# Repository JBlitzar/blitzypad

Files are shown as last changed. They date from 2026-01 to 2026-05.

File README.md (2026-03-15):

# blitzypad

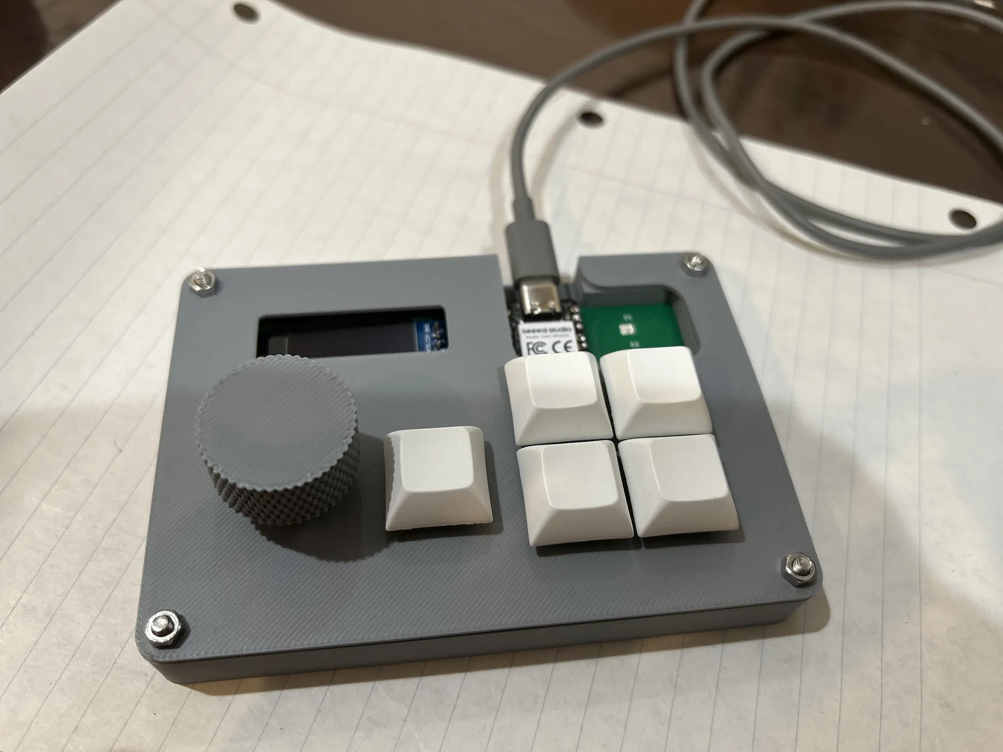
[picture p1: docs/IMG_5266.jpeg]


My starter hackpad project for Blueprint! Has four keys in a grid, an extra key, a rotary encoder, and a 128x32 OLED screen.

I don't have a screenshot of my overall project because it doesn't exist physically yet.

I plan to use this for all sorts of things! General use, sure. Probably also music production with that cool rotary encoder (time scrub / volume control). Or maybe even something like gaming or video editing! That's the beauty of circuitpython. It's really easy and you don't have to reflash every time. I may even try to have some dynamic things on the OLED screen down the line... After all, rp2040 can act as an arbitrary usb device! I've [done](https://github.com/JBlitzar/pd-usb-uvc) [some](https://github.com/JBlitzar/picoducky) [projects](https://github.com/JBlitzar/pd-quad-draw) with those as a part of picoducky ysws. This is really cool because we've got some additional hardware IO (namely the keys, rotary encoder, leds, and screen.)

<table width="100%">
    <tr>
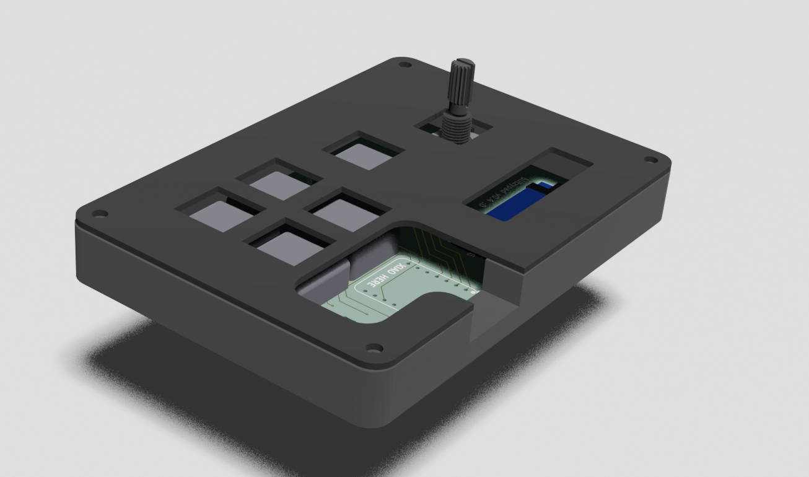
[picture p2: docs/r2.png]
    <td></td>
        <td>
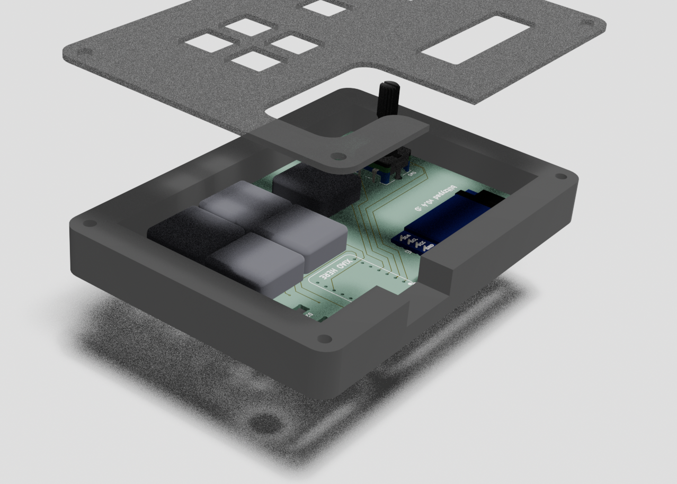
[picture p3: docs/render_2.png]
            
        </td>
        <td>
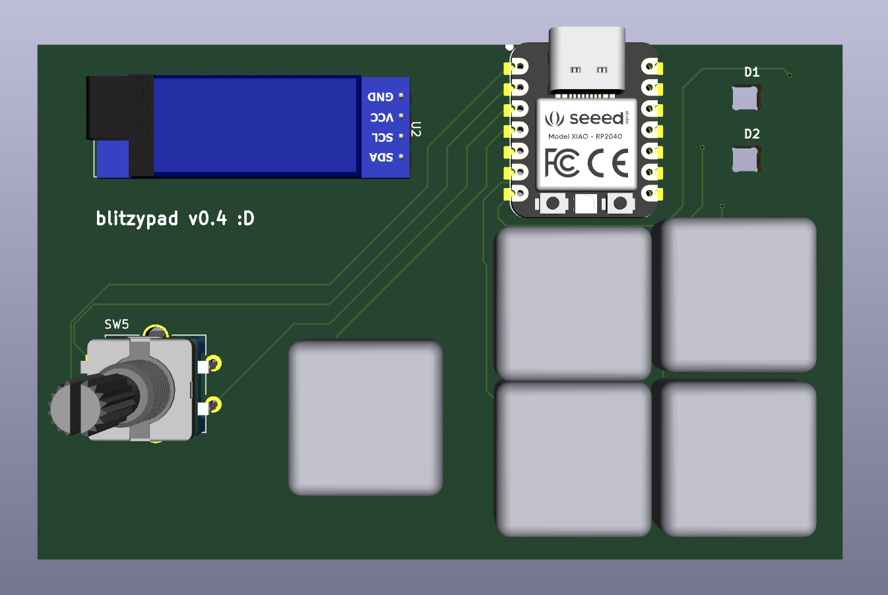
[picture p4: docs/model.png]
            
        </td>
    </tr>
</table>

## Case

_made in Fusion 360_
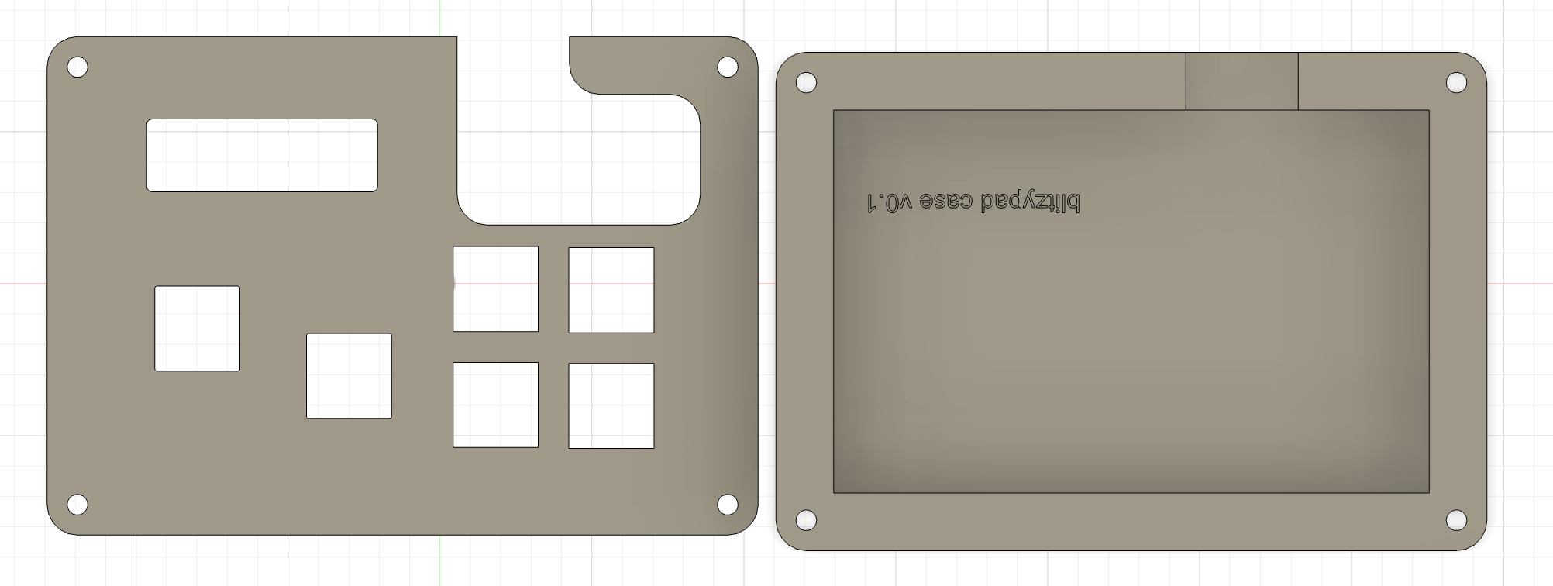
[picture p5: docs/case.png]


I have access to a laser cutter + 3d printer, so I won't need these to be shipped.

## Schematic

_made in Kicad_

### PCB:

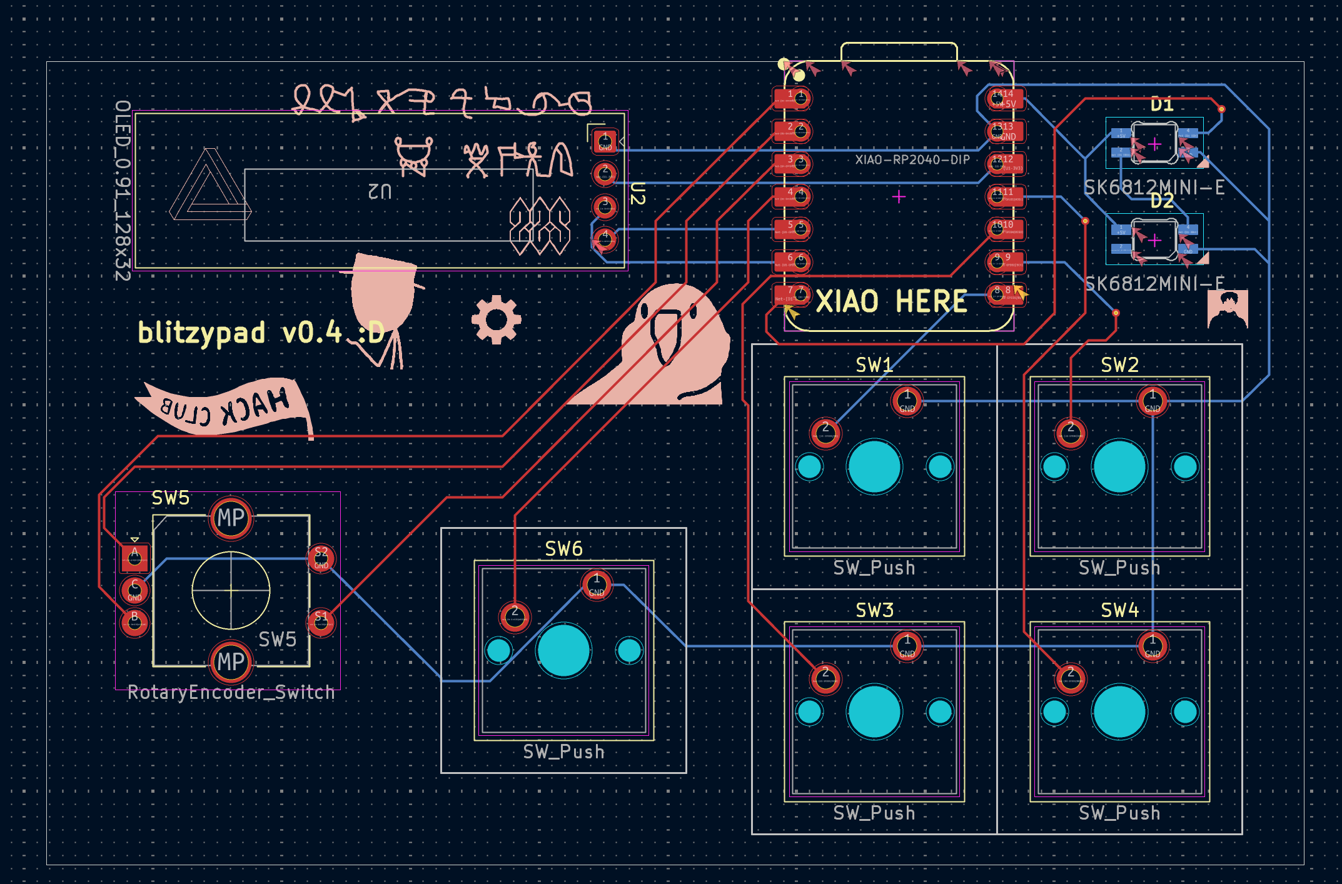
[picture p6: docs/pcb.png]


> I had some fun with the graphics, haha

_clean PCB without silkscreen:_

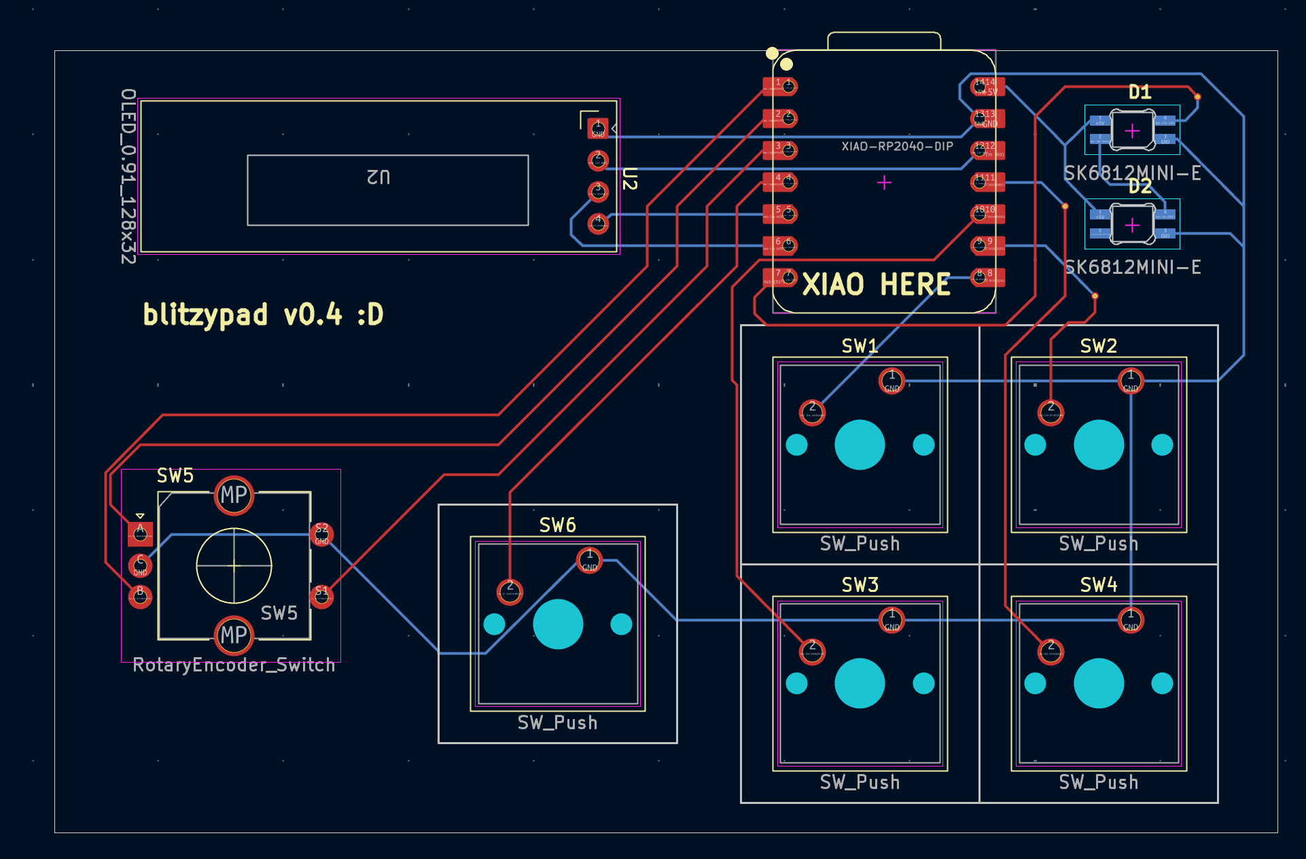
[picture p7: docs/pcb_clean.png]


### Schematic:

> (sorry it's a bit messy)

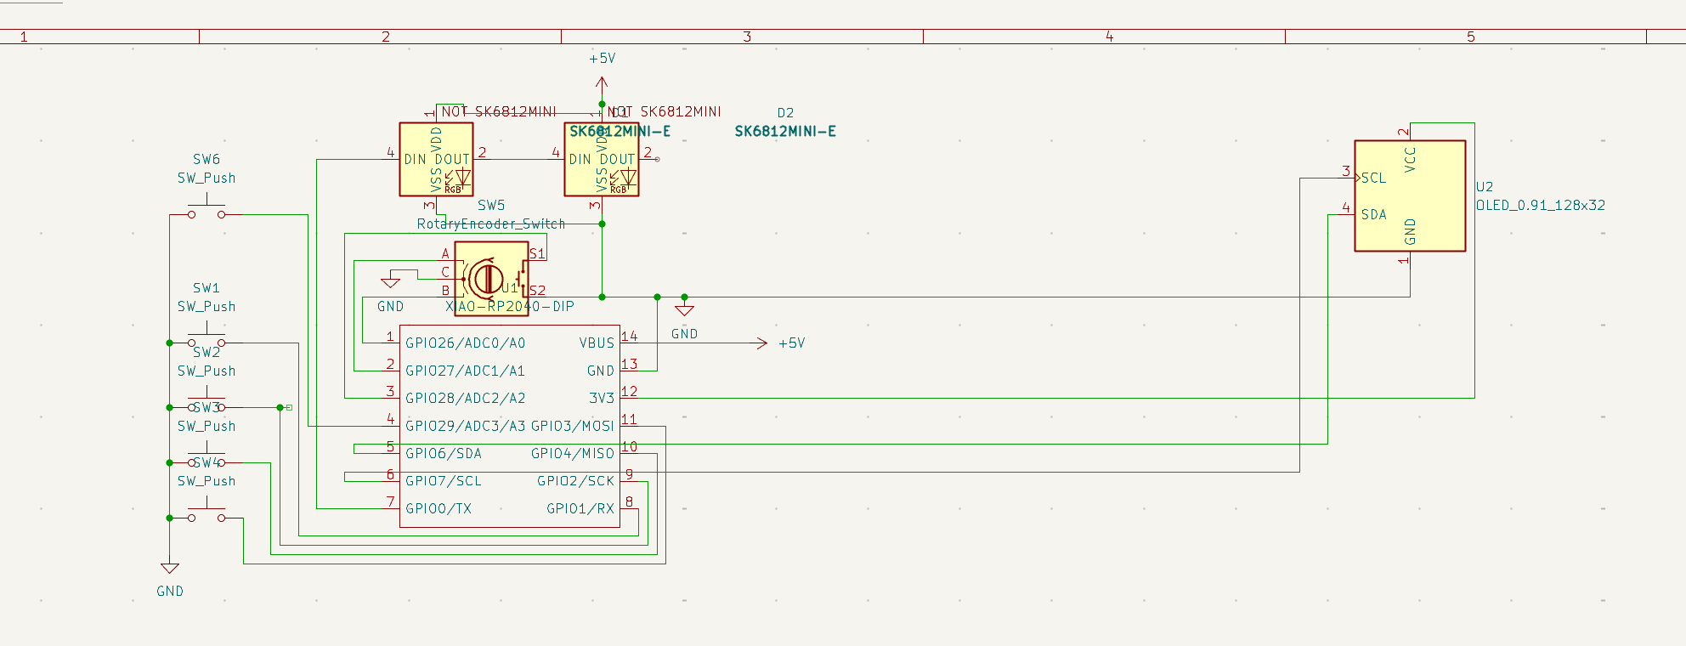
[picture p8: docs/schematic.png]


### Footprints:

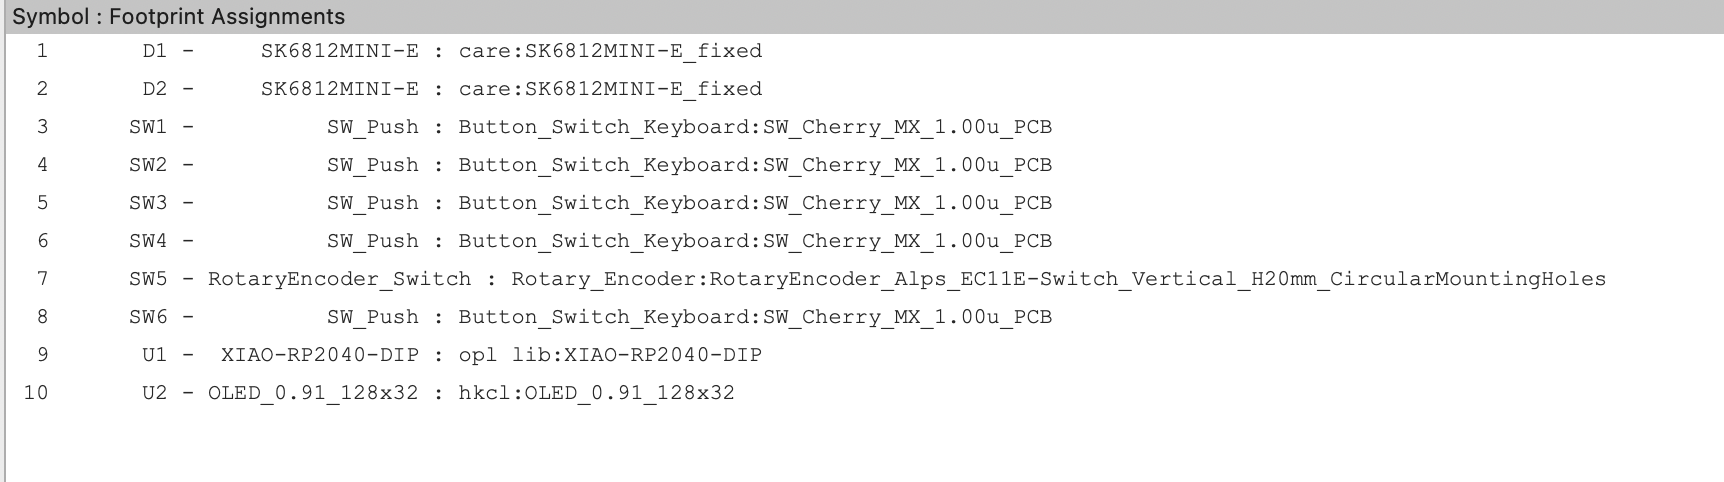
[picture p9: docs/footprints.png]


## BOM:

- 5 Cherry MX Switches
- 5 Keycaps
- 2 SK6812MINI-E LEDs
- 1 0.91" SSD1306 128x32 I2C OLED Display
- 1 Alps rotary encoder, EC12E with switch, vertical shaft.
- 1 XIAO RP2040
- 1 Case
- 4 bolts to hold the case together, I guess?
- 1 male-male USB-C data cable (to plug the xiao in)

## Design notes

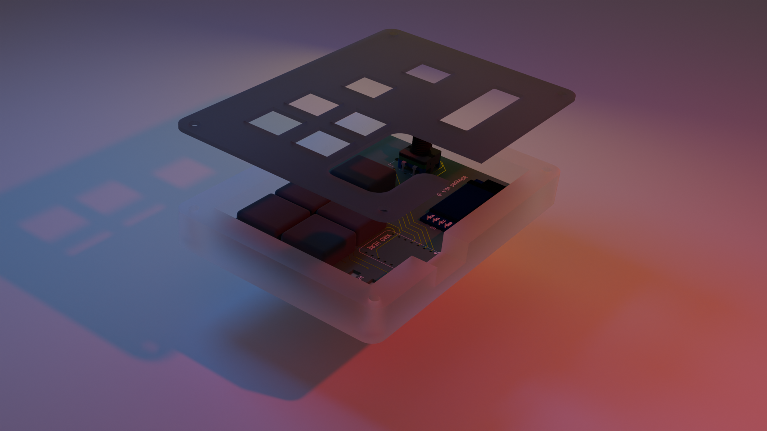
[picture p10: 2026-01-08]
docs/rl.png

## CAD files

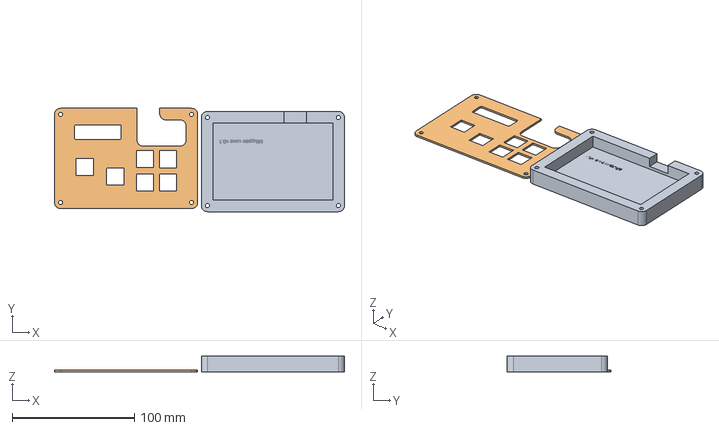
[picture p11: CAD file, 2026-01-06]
CAD/case_full.step
236.9 x 84.6 x 13.0 mm

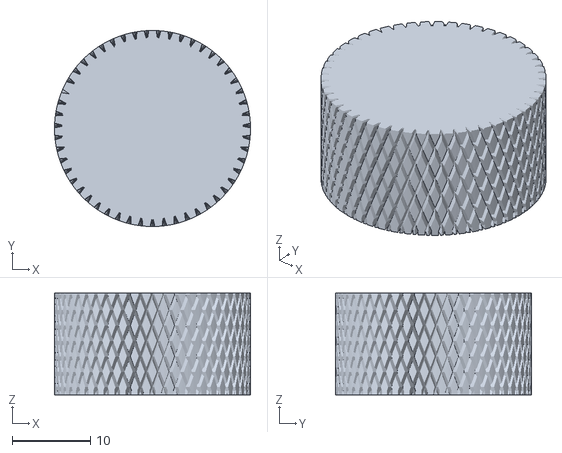
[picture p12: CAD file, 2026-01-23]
CAD/knob.stl
25.0 x 25.0 x 13.0

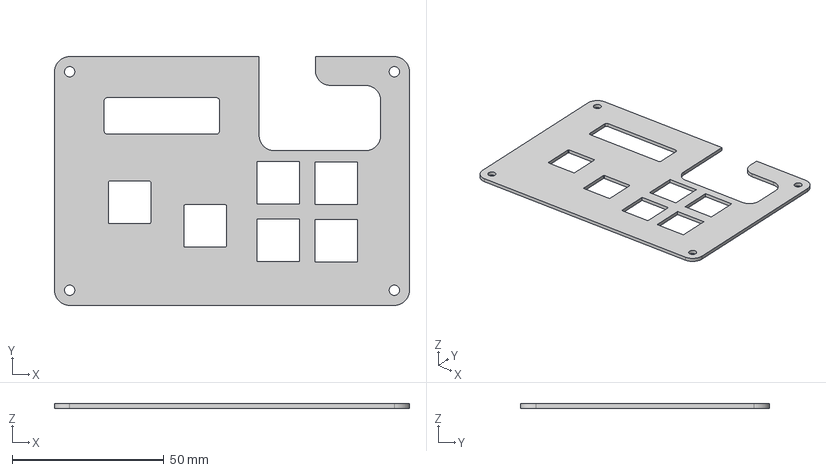
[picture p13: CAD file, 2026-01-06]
CAD/case_top.step
117.0 x 82.0 x 1.50 mm

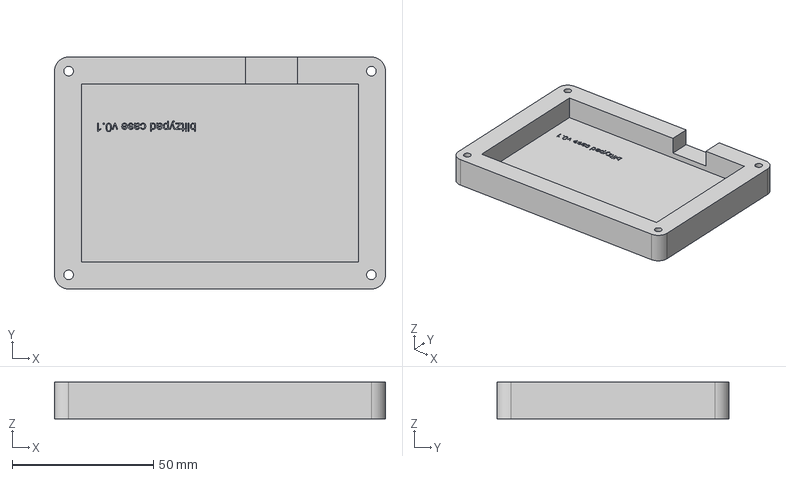
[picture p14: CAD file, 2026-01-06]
CAD/case_bottom.step
117.0 x 82.0 x 13.0 mm

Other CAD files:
CAD/case_bottom_2.step
CAD/blend/blitzypad.blend

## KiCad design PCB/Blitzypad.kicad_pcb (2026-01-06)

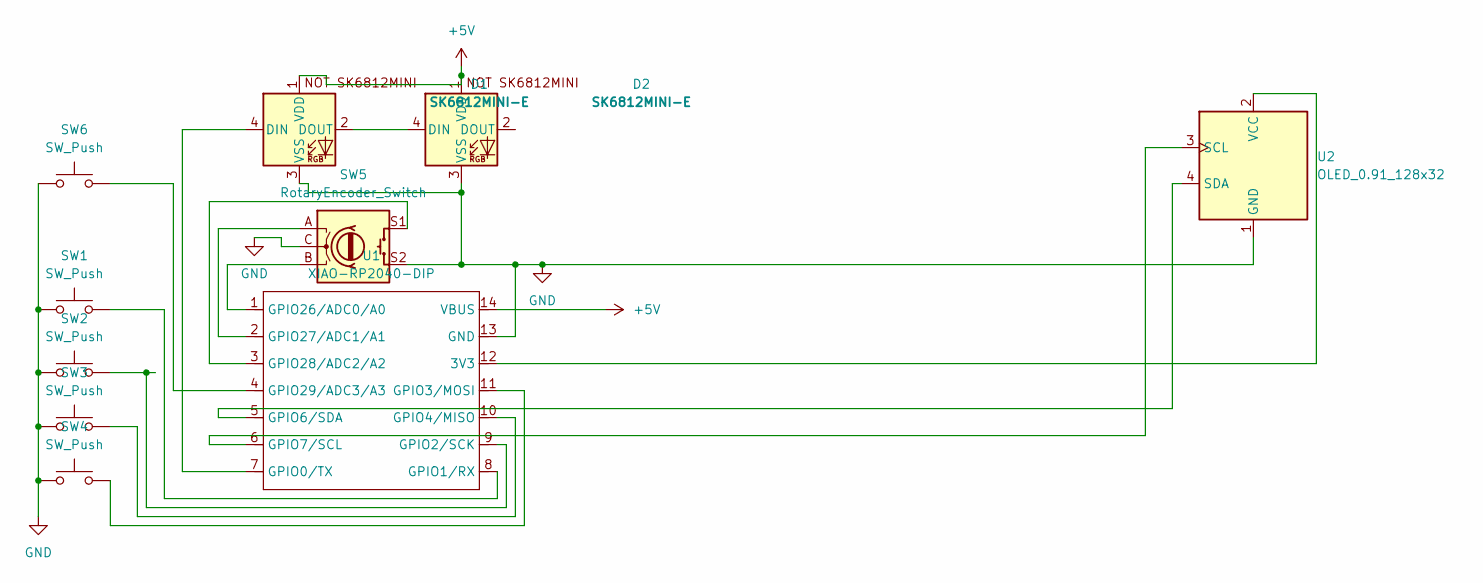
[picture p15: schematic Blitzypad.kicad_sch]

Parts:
D1, D2: SK6812MINI-E; SK6812MINI-E_fixed
SW1, SW2, SW3, SW4, SW6: SW_Push; SW_Cherry_MX_1.00u_PCB
SW5: RotaryEncoder_Switch; RotaryEncoder_Alps_EC11E-Switch_Vertical_H20mm_CircularMoun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
U1: XIAO-RP2040-DIP
U2: OLED_0.91_128x32

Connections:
+5V: D1.1 (VDD), D2.1 (VDD), U1.14 (VBUS)
GND: D1.3 (VSS), D2.3 (VSS), SW1.1, SW2.1, SW3.1, SW4.1, SW5.C, SW5.S2, SW6.1, U1.13 (GND), U2.1 (GND)
unnamed: D1.4 (DIN), U1.7 (GPIO0/TX)
unnamed: D1.2 (DOUT), D2.4 (DIN)
unnamed: U1.12 (3V3), U2.2 (VCC)
unnamed: SW1.2, U1.8 (GPIO1/RX)
unnamed: SW2.2, U1.9 (GPIO2/SCK)
unnamed: SW4.2, U1.11 (GPIO3/MOSI)
unnamed: SW3.2, U1.10 (GPIO4/MISO)
unnamed: U1.5 (GPIO6/SDA), U2.4 (SDA)
unnamed: U1.6 (GPIO7/SCL), U2.3 (SCL)
unnamed: SW5.B, U1.1 (GPIO26/ADC0/A0)
unnamed: SW5.A, U1.2 (GPIO27/ADC1/A1)
unnamed: SW5.S1, U1.3 (GPIO28/ADC2/A2)
unnamed: SW6.2, U1.4 (GPIO29/ADC3/A3)

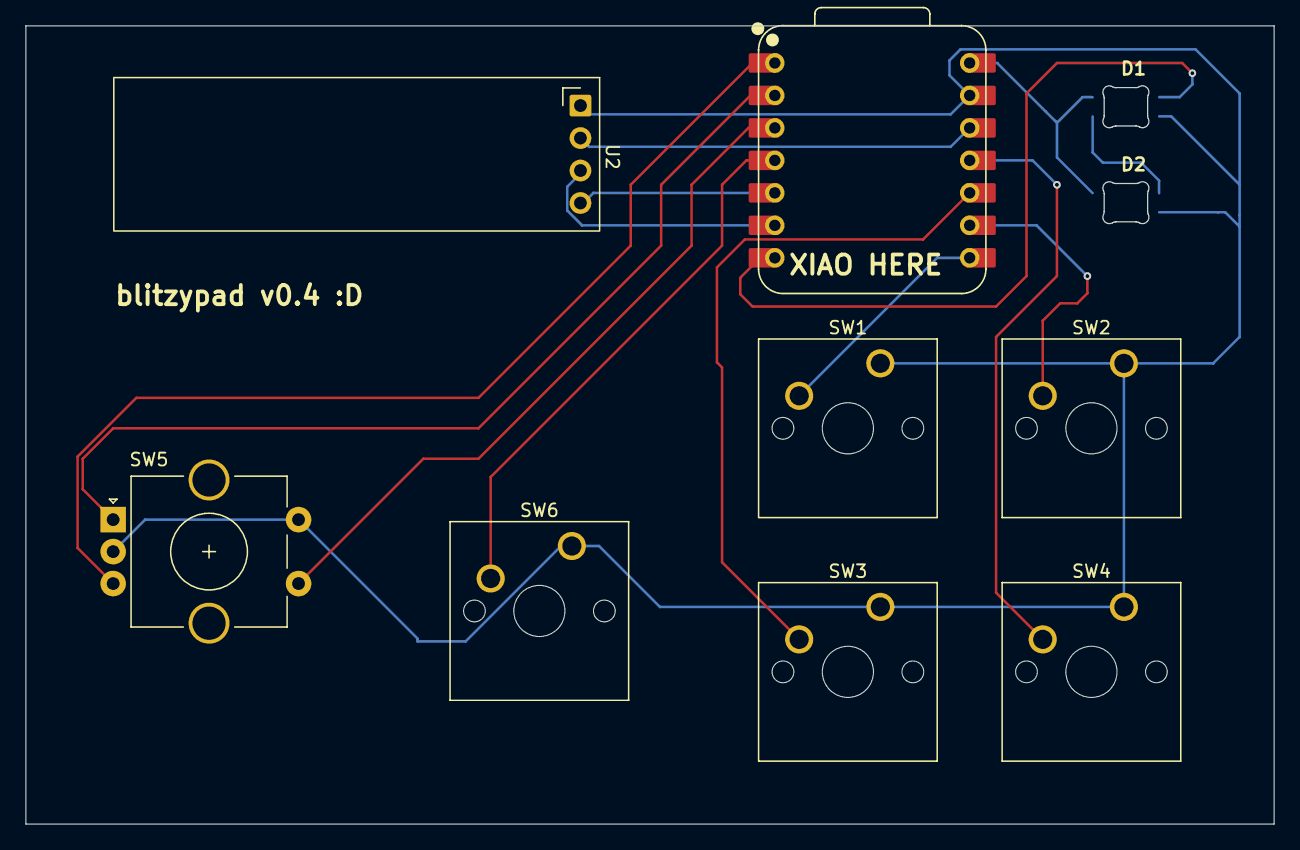
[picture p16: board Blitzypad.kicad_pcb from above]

Board: 2 copper layers, 97.6 x 62.4 mm, 10 parts (0 on the bottom side), 15 nets.

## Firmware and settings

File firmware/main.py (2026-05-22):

import time

import adafruit_displayio_ssd1306
import board
import busio
import digitalio
import displayio
import i2cdisplaybus
import terminalio
import usb_hid
from adafruit_display_text import bitmap_label
from adafruit_hid.consumer_control import ConsumerControl
from adafruit_hid.consumer_control_code import ConsumerControlCode
from adafruit_hid.keyboard import Keyboard
from adafruit_hid.keyboard_layout_us import KeyboardLayoutUS
from adafruit_hid.keycode import Keycode

# time.sleep(3)


# An input action. This can be a keycode, consumer control code, or lambda.
class InputActionType:
    KEYCODE = 1
    CONSUMER_CONTROL = 2
    LAMBDA = 3
    MACRO = 4
    SHORTCUT = 5


class InputAction:
    def __init__(self, value, action_type: int = InputActionType.KEYCODE):
        self.action_type = action_type
        self.value = value

    def perform(
        self,
        keyboard: Keyboard,
        consumer: ConsumerControl,
        layout: KeyboardLayoutUS,
        btn_value: bool = None,
    ):
        if self.action_type == InputActionType.KEYCODE:
            if btn_value is not None:
                if btn_value is False:
                    keyboard.press(self.value)
                else:
                    keyboard.release(self.value)
            else:
                keyboard.press(self.value)
                time.sleep(0.05)
                keyboard.release(self.value)
        elif self.action_type == InputActionType.CONSUMER_CONTROL:
            consumer.send(self.value)
        elif self.action_type == InputActionType.LAMBDA:
            if btn_value is not None:
                if btn_value is True:
                    self.value()
            else:
                self.value()  # I sure do love python dynamic typing
        elif self.action_type == InputActionType.MACRO:
            # type using layout
            if btn_value is not None:
                if btn_value is True:
                    layout.write(self.value)
            else:
                layout.write(self.value)

        elif self.action_type == InputActionType.SHORTCUT:
            # value is a list of keycodes
            if btn_value is not None:
                if btn_value is False:
                    for key in self.value:
                        keyboard.press(key)
                else:
                    for key in self.value:
                        keyboard.release(key)
            else:
                for key in self.value:
                    keyboard.press(key)
                time.sleep(0.05)
                for key in self.value:
                    keyboard.release(key)
        else:
            raise ValueError("Unknown action type")


# a series of modes, each mode has a name and a mapping of inputs to actions (tl, tr, bl, br, enc+enc-)
# extra switches modes
# display current mode
class InputMap:
    def __init__(self, name: str, button_map):
        self.name = name
        self.button_map = button_map

    def get_action_for_button(self, button_index: int):
        return self.button_map.get(button_index, None)


MAPS = [
    # InputMap(
    #     "test",
    #     {
    #         0: InputAction(Keycode.A),
    #         1: InputAction(Keycode.B),
    #         2: InputAction(Keycode.C),
    #         3: InputAction("hello, world!!", InputActionType.MACRO),
    #         4: InputAction(Keycode.E),
    #         5: InputAction(Keycode.F),
    #     },
    # ),
    InputMap(
        "Arrows",
        {
            0: InputAction(Keycode.UP_ARROW),
            1: InputAction(Keycode.RIGHT_ARROW),
            2: InputAction(Keycode.LEFT_ARROW),
            3: InputAction(Keycode.DOWN_ARROW),
            4: InputAction(
                ConsumerControlCode.VOLUME_INCREMENT, InputActionType.CONSUMER_CONTROL
            ),
            5: InputAction(
                ConsumerControlCode.VOLUME_DECREMENT, InputActionType.CONSUMER_CONTROL
            ),
        },
    ),
    InputMap(
        "programming",
        {
            0: InputAction(
                "#include <iostream>\n#include <vector>\nusing namespace std;\n\nint main() {\ncin.tie(0);ios_base::sync_with_stdio(false);\nreturn 0;\n\n",
                InputActionType.MACRO,
            ),
            1: InputAction("for(int i =0; i < n; i++){", InputActionType.MACRO),
            2: InputAction("vector<int> vec;", InputActionType.MACRO),
            3: InputAction(
                'void print_vec(vector<int> vec){\nfor(int i=0;i<vec.size();i++){\ncout << vec[i];\n\ncout << "\\n";',
                InputActionType.MACRO,
            ),
            4: InputAction(
                [Keycode.OPTION, Keycode.LEFT_ARROW], InputActionType.SHORTCUT
            ),
            5: InputAction(
                [Keycode.OPTION, Keycode.RIGHT_ARROW], InputActionType.SHORTCUT
            ),
        },
    ),
    InputMap(
        "null",
        {
            0: InputAction(lambda: None, InputActionType.LAMBDA),
            1: InputAction(lambda: None, InputActionType.LAMBDA),
            2: InputAction(lambda: None, InputActionType.LAMBDA),
            3: InputAction(lambda: None, InputActionType.LAMBDA),
            4: InputAction(lambda: None, InputActionType.LAMBDA),
            5: InputAction(lambda: None, InputActionType.LAMBDA),
        },
    ),
    InputMap(
        "blender",
        {
            0: InputAction(
                [Keycode.CONTROL, Keycode.ALT, Keycode.KEYPAD_ZERO],
                InputActionType.SHORTCUT,
            ),
            1: InputAction(Keycode.G),
            2: InputAction(Keycode.R),
            3: InputAction(Keycode.F12),
            4: InputAction(
                ConsumerControlCode.VOLUME_INCREMENT, InputActionType.CONSUMER_CONTROL
            ),
            5: InputAction(
                ConsumerControlCode.VOLUME_DECREMENT, InputActionType.CONSUMER_CONTROL
            ),
        },
    ),
    InputMap(
        "figma",
        {
            0: InputAction(Keycode.P),
            1: InputAction(
                [Keycode.SHIFT, Keycode.P],
                InputActionType.SHORTCUT,
            ),
            2: InputAction(Keycode.V),
            3: InputAction(
                [Keycode.SHIFT, Keycode.TWO],
                InputActionType.SHORTCUT,
            ),
            4: InputAction(Keycode.TAB),
            5: InputAction(
                [Keycode.SHIFT, Keycode.TAB],
                InputActionType.SHORTCUT,
            ),
        },
    ),
]

MAP = MAPS[0]


class DebouncedInput:
    def __init__(self, pin: digitalio.DigitalInOut, debounce_s: float = 0.02):
        self.pin = pin
        self.debounce_s = debounce_s
        self._last_raw = pin.value
        self.value = pin.value
        self._last_change_t = time.monotonic()

    def update(self, now: float) -> bool:
        raw = self.pin.value
        if raw != self._last_raw:
            self._last_raw = raw
            self._last_change_t = now
        if (now - self._last_change_t) >= self.debounce_s and raw != self.value:
            self.value = raw
            return True
        return False


class RotaryEncoder:
    _TRANSITIONS = {
        (0b00, 0b01): +1,
        (0b01, 0b11): +1,
        (0b11, 0b10): +1,
        (0b10, 0b00): +1,
        (0b00, 0b10): -1,
        (0b10, 0b11): -1,
        (0b11, 0b01): -1,
        (0b01, 0b00): -1,
    }

    def __init__(
        self,
        a: digitalio.DigitalInOut,
        b: digitalio.DigitalInOut,
        steps_per_detent: int = 2,
    ):
        self.a = a
        self.b = b
        self.steps_per_detent = steps_per_detent
        self._prev = self._read_state()
        self._accum = 0

    def _read_state(self) -> int:
        return ((1 if self.a.value else 0) << 1) | (1 if self.b.value else 0)

    def update(self) -> int:
        cur = self._read_state()
        if cur == self._prev:
            return 0
        step = self._TRANSITIONS.get((self._prev, cur), 0)
        self._prev = cur
        if step == 0:
            return 0
        self._accum += step
        if self._accum >= self.steps_per_detent:
            self._accum = 0
            return +1
        if self._accum <= -self.steps_per_detent:
            self._accum = 0
            return -1
        return 0


def _make_input(pin_id) -> digitalio.DigitalInOut:
    pin = digitalio.DigitalInOut(pin_id)
    pin.direction = digitalio.Direction.INPUT
    pin.pull = digitalio.Pull.UP
    return pin


keyboard = Keyboard(usb_hid.devices)
consumer = ConsumerControl(usb_hid.devices)
layout = KeyboardLayoutUS(keyboard) if KeyboardLayoutUS else None

btn_tl = DebouncedInput(_make_input(board.D7))
btn_tr = DebouncedInput(_make_input(board.D8))
btn_bl = DebouncedInput(_make_input(board.D9))
btn_br = DebouncedInput(_make_input(board.D10))
extra_btn = DebouncedInput(_make_input(board.D3))

enc_a = _make_input(board.A1)
enc_b = _make_input(board.A0)

encoder = RotaryEncoder(enc_a, enc_b)

# buttons = [
#     (btn_tl, Keycode.W),
#     (btn_tr, Keycode.D),
#     (btn_bl, Keycode.A),
#     (btn_br, Keycode.S),
# ]

buttons = [btn_tl, btn_tr, btn_bl, btn_br]


# try:
#     import neopixel
#     pixels = neopixel.NeoPixel(board.D0, 2, brightness=0.3, auto_write=True)
#     pixels.fill((0, 0, 20))
# except ImportError:
#     pixels = None


sda, scl = board.SDA, board.SCL
i2c = busio.I2C(scl, sda)
display_bus = i2cdisplaybus.I2CDisplayBus(i2c, device_address=0x3C)
display = adafruit_displayio_ssd1306.SSD1306(display_bus, width=128, height=64)

lbl = bitmap_label.Label(
    terminalio.FONT,
    text="\nready\n",
    color=0xFFFFFF,
    label_direction="UPD",
)
lbl.anchor_point = (0.5, 0.5)
lbl.scale = 2
lbl.anchored_position = (display.width // 2, display.height // 2)

group = displayio.Group()
group.append(lbl)
display.root_group = group


def _set_status(text: str) -> None:
    try:
        lbl.text = f"\n{text}\n"
    except Exception:
        pass


while True:
    now = time.monotonic()
    for btn in buttons:
        if btn.update(now):
            InputAction.perform(
                MAP.get_action_for_button(buttons.index(btn)),
                keyboard,
                consumer,
                layout,
                btn.value,
            )
    if extra_btn.update(now) and extra_btn.value is False:
        MAP = MAPS[(MAPS.index(MAP) + 1) % len(MAPS)]
        _set_status(MAP.name)
    detent = encoder.update()
    if detent == +1:
        InputAction.perform(
            MAP.get_action_for_button(len(buttons)),
            keyboard,
            consumer,
            layout,
        )
    elif detent == -1:
        InputAction.perform(
            MAP.get_action_for_button(len(buttons) + 1),
            keyboard,
            consumer,
            layout,
        )
    # if enc_sw.update(now) and enc_sw.value is False:
    #     consumer.send(ConsumerControlCode.MUTE)
    #     _set_status("mute")
    time.sleep(0.001)

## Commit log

2026-01-05 upload everything
    [Blitzypad.kicad_pcb, Blitzypad.kicad_sch, blitzypad_case_full_1.step]
2026-01-05 Add top and bottom as separate files
    [case_bottom_1.step, case_top_1.step]
2026-01-06 Apply fixes according to feedback
    [Blitzypad.kicad_pcb]
2026-01-06 small pcb changes to make it look nicer
    [Blitzypad.kicad_pcb, Blitzypad.kicad_sch]
2026-01-06 new case
    [blitzypad_case_full_1.step, case_bottom_1.step, case_bottom_2.step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]
